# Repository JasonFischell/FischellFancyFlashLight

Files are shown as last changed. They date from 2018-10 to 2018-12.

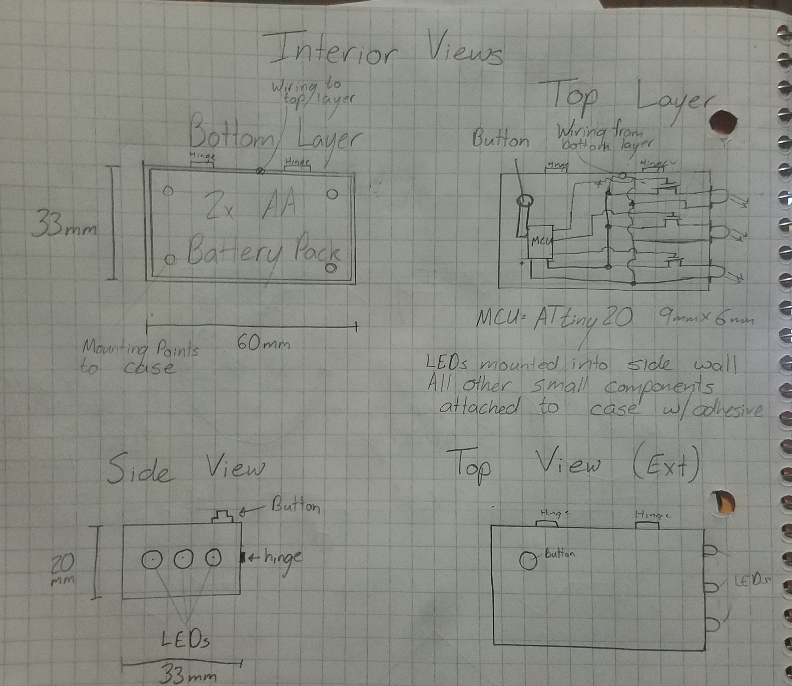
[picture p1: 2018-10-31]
Mechanical/Milestone 2/Original Flashlight Schematic.jpg

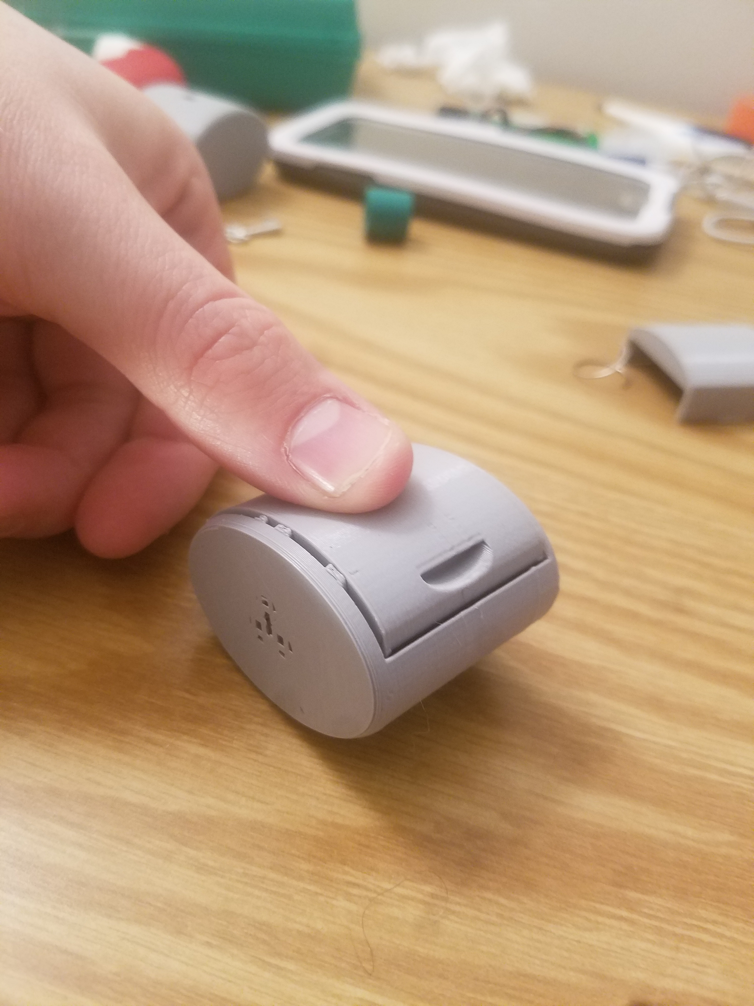
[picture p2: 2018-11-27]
Testing/Hardware Testing/20181126_164808.jpg

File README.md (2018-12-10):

# FischellFancyFlashLight

## Mechanical
A 3D printed case was designed to minimize the size of the device while maintaining a comfortable shape and relative stability. The dimensions are 1.2"x1.8"x2", with a 0.33" deep alcove for the 3 LEDs. The button is flush with the surface of the case, and debounce is performed in software, not hardware. The case is in two parts. The bottom is larger, containing conical holes to for ease of insertion of the LEDs and buttons, and four corner standoffs for the PCB. There are also two alcoves in the bottom for clips to attach the top to the bottom, and two semicircular holes of 0.4" diameter for pinching the top of the case to release the clasps. The top is smaller, with 0.01" of clearance on all sides to fit in the 1.3"x1.5" hole. The clips themselves have 0.05"x0.01"x0.01" clearance on all sides. Printed with 0.8mm wall thickness, 0.2mm layers, and 8% infill, the fit is incredibly tight, making the case very durable without any connective materials. The PCB cannot rattle around in the case due to the tightness and the conical standoffs, and neither can the top relative to the bottom. The case is so durable that it can be thrown at an 8 foot ceiling and fall on to linoleum without any damage. 

## Electrical 
The PCB is 1.25"x1.1" with a 0.05" hole in each corner for the standoffs. The three white (roughly 3.1V voltage drop) LEDs are driven by a MOSFET and connected in series with 10 Ohm resistors. The entire system is controlled by an ATTiny85, which is put into sleep mode for power conservation in the off state. Finally, there are 6 pins connected to the 6 programming pins on the ATTiny so that it can be reprogrammed at any point. A voltage regulator drops the voltage from roughly 6V to 3V, but the system works with a single 3V battery as well. The flashlight has current draws and theoretical battery lives are as follows:

						Battery Life (2 series,	Battery Life 
State:	Current Draw:	320 mAh CR2430):		(1, 1 Ah CR2477): 
Off		34.81 uA		9193 hr = 383 days		28727 hr = 1197 days = 3.28 years
Low		7.300 mA		43.8 hr = 1.83 days		137.0 hr = 5.71 days
Med		22.515 mAh		14.2 hr = 0.59 days		44.41 hr = 1.85 days
High	62.198 mAh		5.14 hr = 0.21 days		16.08 hr = 0.67 days
Flash 	4 mA - 62 mAh	9.70 hr = 0.40 days		30.30 hr = 1.26 days

## Software 
The code is incredibly simple, with interrupts for the button presses, PWM to controll LED brightness, and simple time difference calculation to prevent two button presses within 50 ms (to prevent button bouncing). To reprogram the flashlight, disconnect the batteries and connect the pins on the ribbon cables as follows:

Color: 		ATTiny Pin (PB pin, Mech.):		Arduino Pin:
Red 		Reset (NA, 1) 					Pin 10
Orange 		SCK (2, 7)						Pin 13
Yellow 		MISO (1, 6)						Pin 12
Green		Vcc	(NA, 8)						Power (3.3V or 5V)
Blue 		MOSI (0, 5)						Pin 11
Purple		Ground (NA, 4)					Ground

## Testing 
Every flashlight case ever printed was immeadiately drop tested. The electronic hardware was tested on a breadboard, and the current was tested using a high precision multimeter and an laboratory power supply (see above).

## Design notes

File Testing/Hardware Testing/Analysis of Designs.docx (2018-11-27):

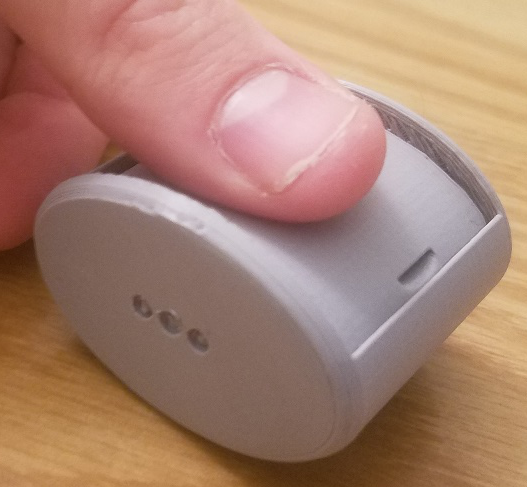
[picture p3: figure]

Velcro Design 1 (left): This case was designed to be held together by Velcro between the top and bottom pieces. The width of two layers of Velcro was guessed at 0.25”, but this proved to be roughly 0.15” too large, as indicated by the fact that top is not flush with the top of the outer casing.

Separation was to be achieved by inserting fingernails into the slits on either side of the top. However, 0.3” was not nearly wide enough (see thumb for scale) and the depth of 0.1” (bottom) was also too shallow.

Finally, the 3 LEDs were intended to be places in a row, but this design was later revised.

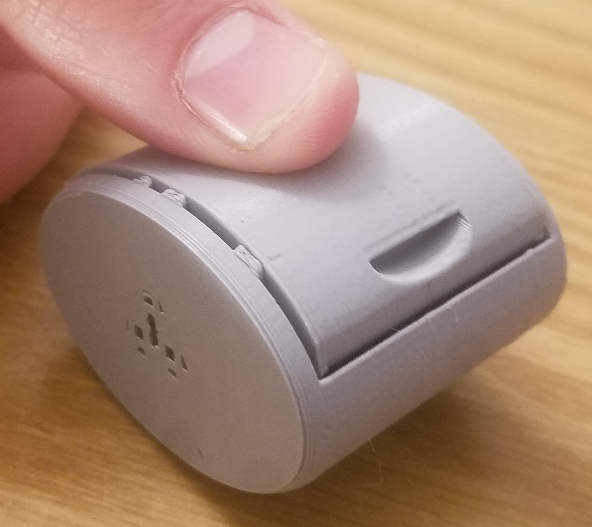
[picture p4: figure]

Velcro Design 2 (right): Same as the above, but the width of strips of Velcro was adjusted so that the top would be flush with the top of the outer casing.

The nail indents were doubled in width to 0.6” and the depth was increased to 0.15”, making the indents comfortable to grip with most fingers.

Next, the top was made wider to accommodate the increased depth of the fingernail indents.

Finally, the configuration of the 3 LEDs was changed, but this did not print correctly. This was fixed in future generations.

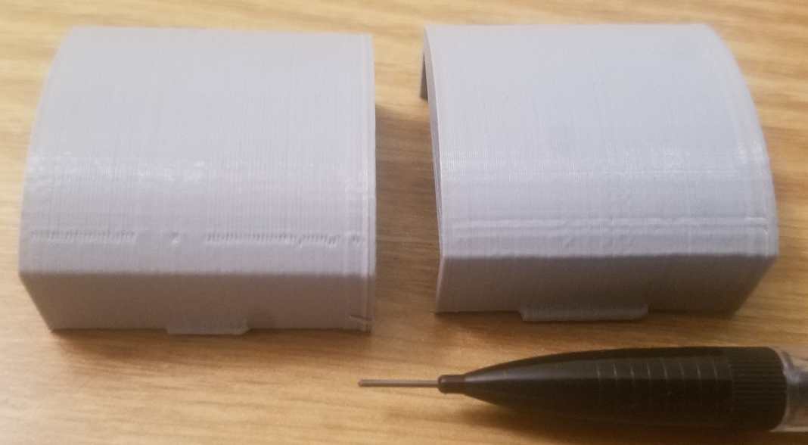
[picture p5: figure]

Clip Design 1 (left) and 2 (right):

The clip design is very similar to the Velcro, with the exception of the fastening method. On the left, there is a 0.3”x0.03”x0.03” protrusion on either side of the top, with a corresponding (but slightly larger) indent on either side of the bottom. This was too loose, and so in generation 2, the protrusion was adjusted to 0.5”x0.05”x0.05”. This fits tightly into the larger holes on the bottom of the housing, making the top removable, but difficult to remove. Both protrusions possess a 0.03” fillet to increase structural integrity. 0.7mm lead is shown for scale.

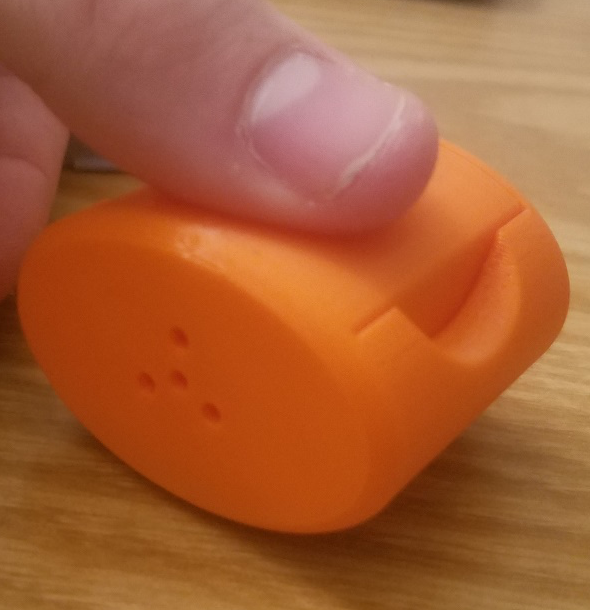
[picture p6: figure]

3D Printer Settings for Clip Design 2:

As is shown in this image, the bottom contains 1 holes for the 3 signal wires of the 3 LEDs on the front (outside) and 1 central hole for the common ground wires of the LEDs, placing them in a circular pattern on the face of the flashlight. The bottom has a semicircular 0.8” diameter hole cut in either side, 0.05” above the indentation for the clips protruding from the top. These holes allow the user to pinch the sides of the top together, thereby removing the protrusions from their holes and allowing the top to be removed. The thumb, shown for scale, was the appropriate width for such protrusions.

The remaining question is what 3D printer settings allow sufficiently easy bending of the top piece to remove the protrusions from the holes in the bottom, without jeopardizing the structural integrity of the casing. It was determined that wall width (0.4 mm vs. 0.8 mm) played a much bigger role in flexibility and integrity than infill. The 0.4 mm wall width top can easily be removed by pinching the sides of the top and pulling, whereas the 0.8 mm wall width top requires an inordinate amount of force (or the use of a screwdriver to pry it open) to remove the top. In the end, the choice between these two is somewhat arbitrary, but I am leaning toward the 0.8 mm wall width in the hope that it will be able to survive a fall from any height due to its relatively low terminal velocity.

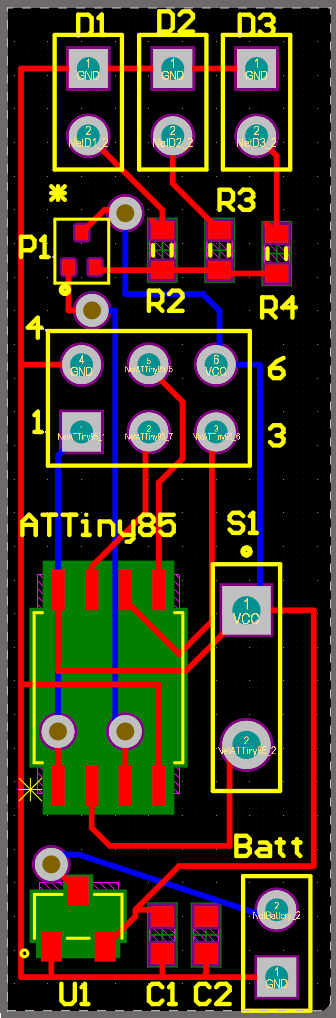
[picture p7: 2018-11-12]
Electronics/Milestone 4/PCB.png

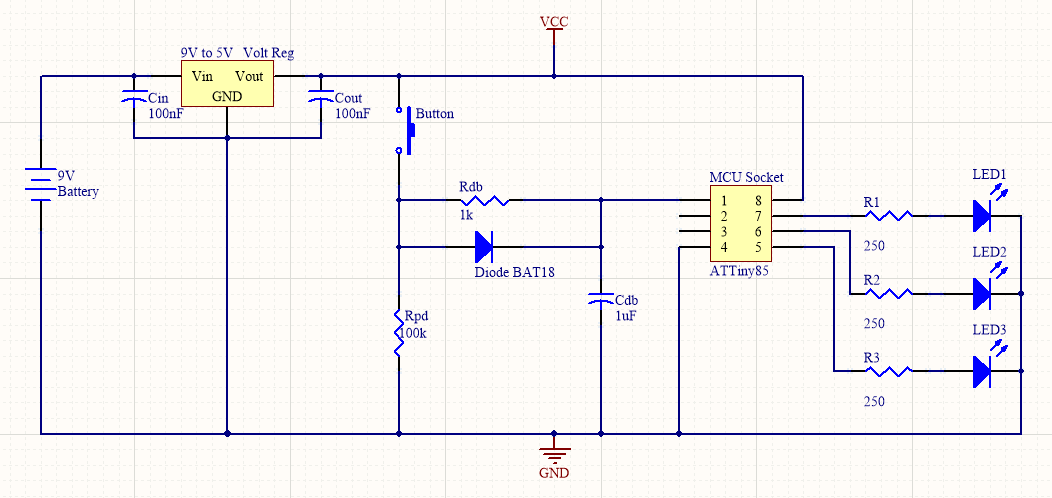
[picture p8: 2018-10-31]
Electronics/Milestone 3/Milestone_3_-_Schematic.png

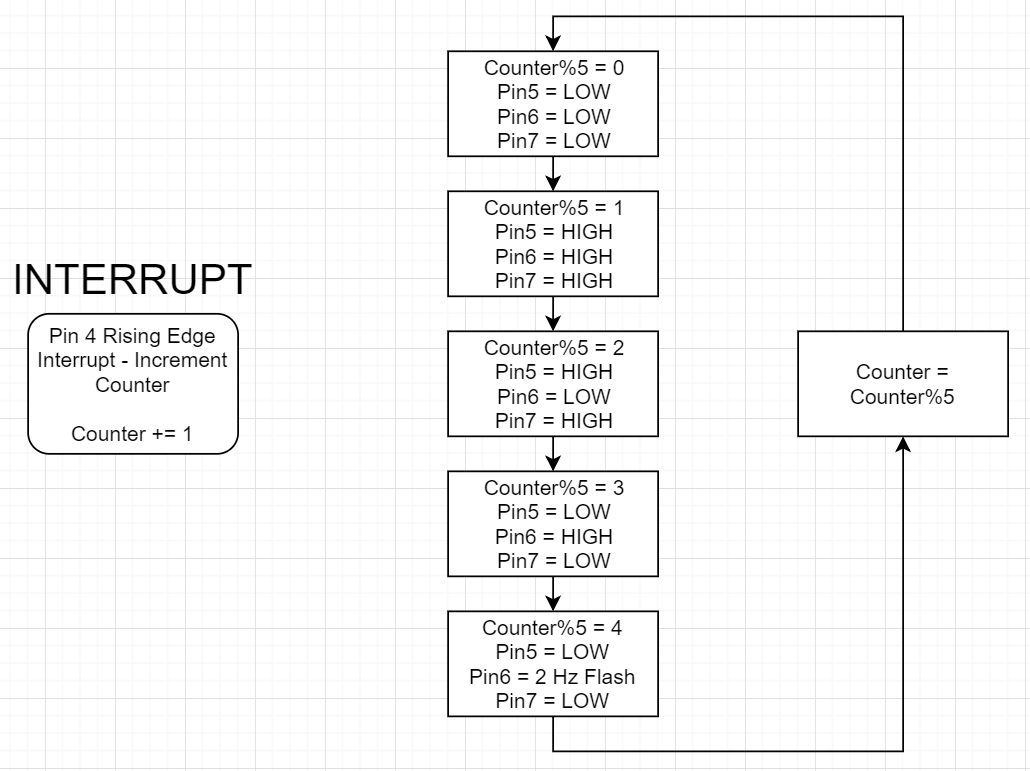
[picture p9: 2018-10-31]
Software/Milestone 3/Milestone_3_-_Software_Flowchart.png

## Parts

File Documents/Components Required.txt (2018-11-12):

Components required:
Already Have:
ATTiny85
Button

Need:
5 ohm resistor 0603 .25 W x3
100 kohm resistor 0603 0.1W x1
1 uF capacitor 0603 x2
Schottky diode 0603 with smallest voltage drop/power consumption possible x3

Battery Holder x3
https://www.digikey.com/product-detail/en/keystone-electronics/1025/36-1025-ND/49949

TVS Diode 
https://www.digikey.com/product-detail/en/littelfuse-inc/SMAJ5.0A/SMAJ5.0ALFCT-ND/762462

Linear Regulator 3.3 V
https://www.digikey.com/product-detail/en/diodes-incorporated/AP2120N-3.3TRG1/AP2120N-3.3TRG1DICT-ND/4505261

N-Channel MOSFET
https://www.digikey.com/product-detail/en/rohm-semiconductor/RE1C002UNTCL/RE1C002UNTCLCT-ND/5042535

White led through hole (non-specific at this point) x3

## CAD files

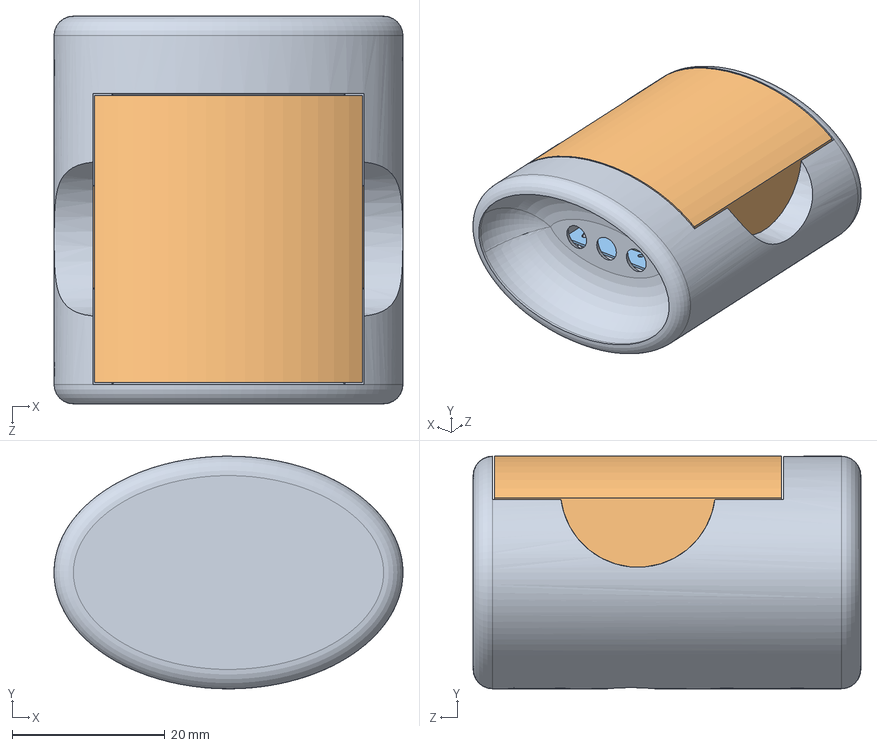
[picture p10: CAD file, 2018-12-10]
Mechanical/Milestone 5/Assem1.SLDASM
45.7 x 30.5 x 50.8 mm
Final Case Bottom
Final Case Top
Board_1
keystone-PN1025-7_1
SOT23-3_1
Extruded_1
Extruded_1_2 x 3
Extruded_1_3
Extruded_1_4
Extruded_1_5
8S2_1

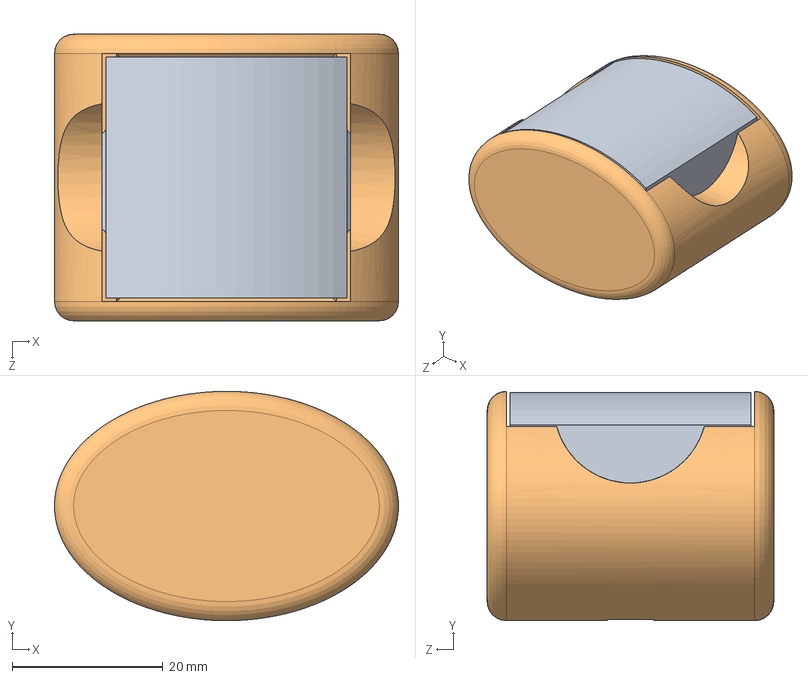
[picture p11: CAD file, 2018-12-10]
Mechanical/Milestone 5/Clip Assembly.SLDASM
45.7 x 30.5 x 38.1 mm
Clip Top
Clip Bottom
Board_1
keystone-PN1025-7_1
SOT23-3_1
Extruded_1
Extruded_1_2 x 3
Extruded_1_3
Extruded_1_4
Extruded_1_5
8S2_1

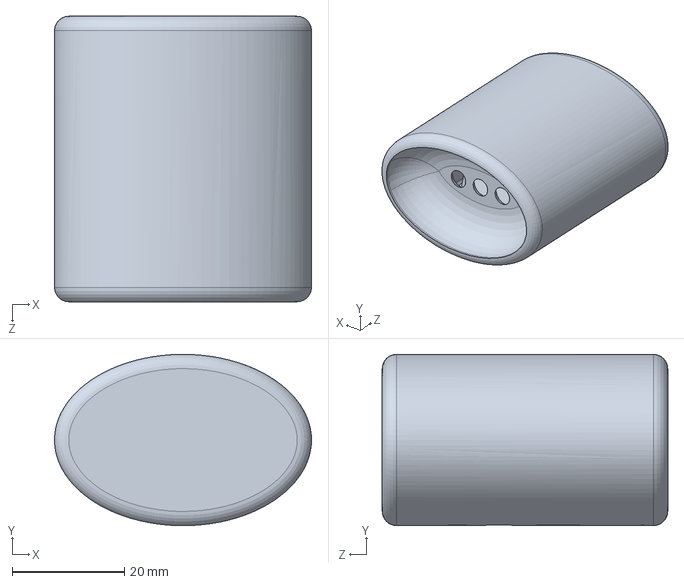
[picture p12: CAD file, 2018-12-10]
Mechanical/Milestone 5/Whole Final Case.SLDPRT
45.7 x 30.5 x 50.8 mm

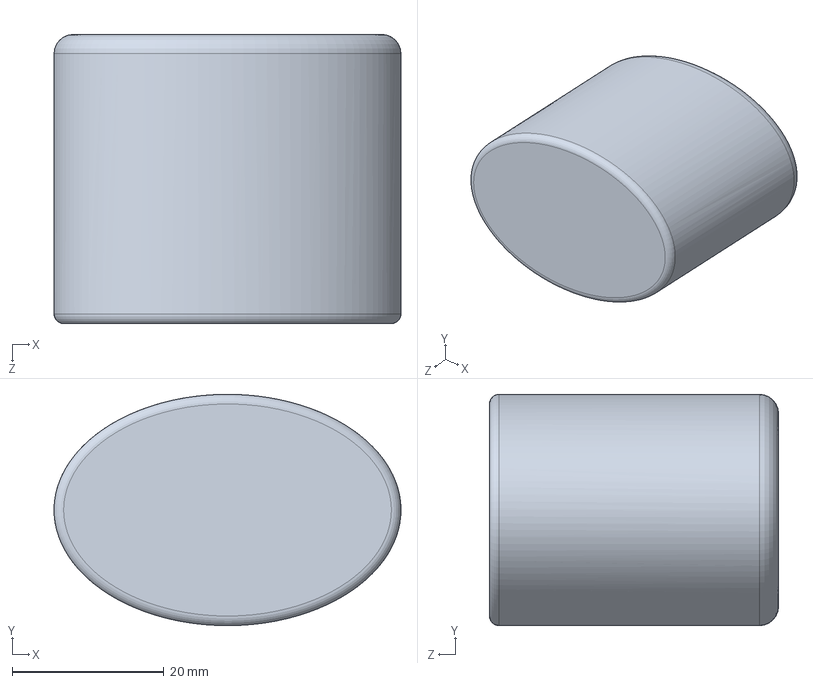
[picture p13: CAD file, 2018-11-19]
Mechanical/Milestone 5/Whole Case Incomplete.SLDPRT
45.7 x 30.5 x 38.1 mm

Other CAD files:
Mechanical/Milestone 5/U1_1.sldasm
Mechanical/Milestone 5/C2_1.sldasm
Mechanical/Milestone 5/C1_1.sldasm
Mechanical/Milestone 5/Imported_1.sldasm
Mechanical/Milestone 5/R3_1.sldasm
Mechanical/Milestone 5/R4_1.sldasm
Mechanical/Milestone 5/R2_1.sldasm
Mechanical/Milestone 5/R1_1.sldasm
Mechanical/Milestone 5/ATTiny85_1.sldasm
Mechanical/Milestone 5/Velcro Assembly.SLDASM
Mechanical/Milestone 5/Successful Assembly.SLDASM
Mechanical/Milestone 5/R1.sldasm
Mechanical/Milestone 5/C1.sldasm
Mechanical/Milestone 5/C2.sldasm
Mechanical/Milestone 5/4438510656.sldasm
Mechanical/Milestone 5/4438510848.sldasm
Mechanical/Milestone 5/4438511040.sldasm
Mechanical/Milestone 5/4438511232.sldasm
Mechanical/Milestone 5/4438511424.sldasm
Mechanical/Milestone 5/5808184704.sldasm
Mechanical/Milestone 5/5808184896.sldasm
Mechanical/Milestone 5/5808185088.sldasm
Mechanical/Milestone 5/5808185280.sldasm
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

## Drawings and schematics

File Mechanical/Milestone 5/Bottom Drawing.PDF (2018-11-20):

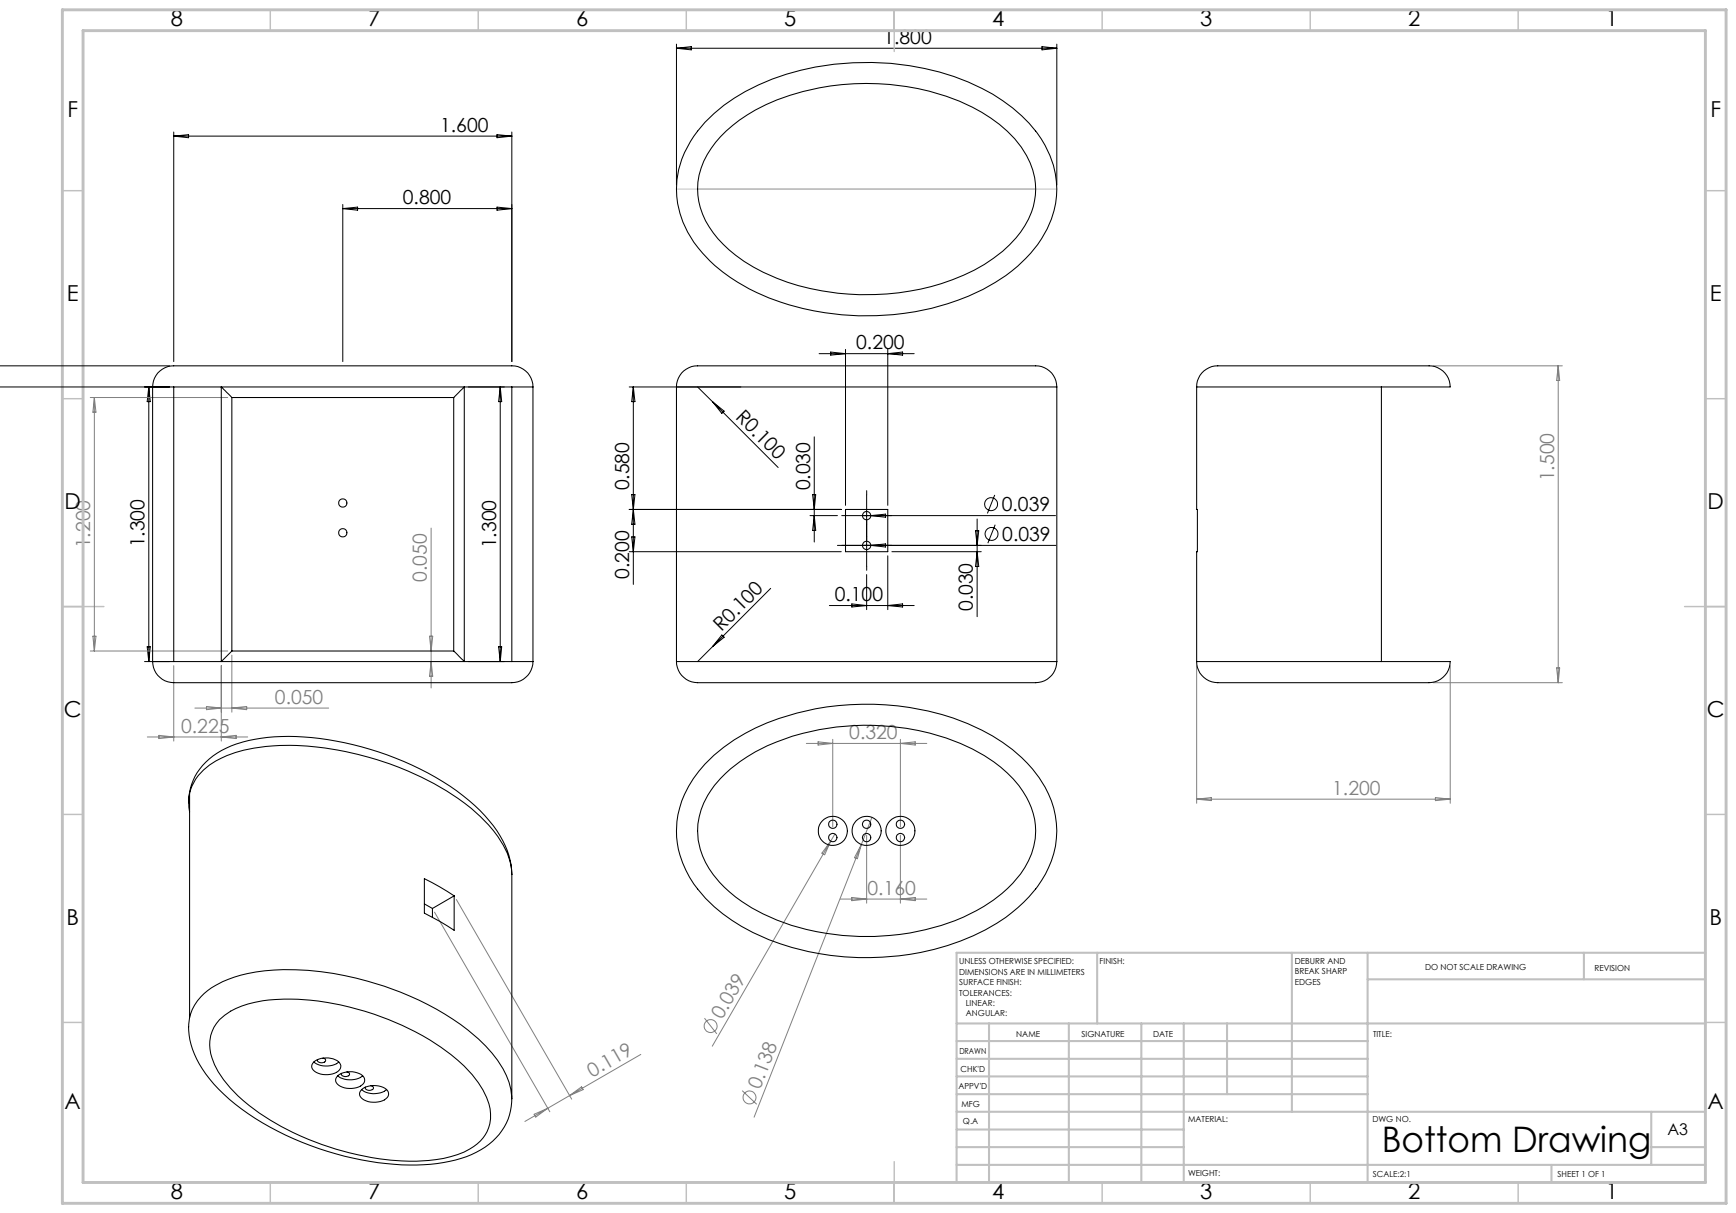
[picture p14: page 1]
FINISH:; DEBURR AND; BREAK SHARP; DO NOT SCALE DRAWING; REVISION; SCALE:2:1; SHEET 1 OF 1

UNLESS OTHERWISE SPECIFIED:
DIMENSIONS ARE IN MILLIMETERS
SURFACE FINISH:
TOLERANCES:
LINEAR:
ANGULAR:

NAME | SIGNATURE | DATE | | | | TITLE:

DRAWN
CHK'D
APPV'D
MFG
Q.A | | | | MATERIAL: | DWG NO. Bottom Drawing | A3

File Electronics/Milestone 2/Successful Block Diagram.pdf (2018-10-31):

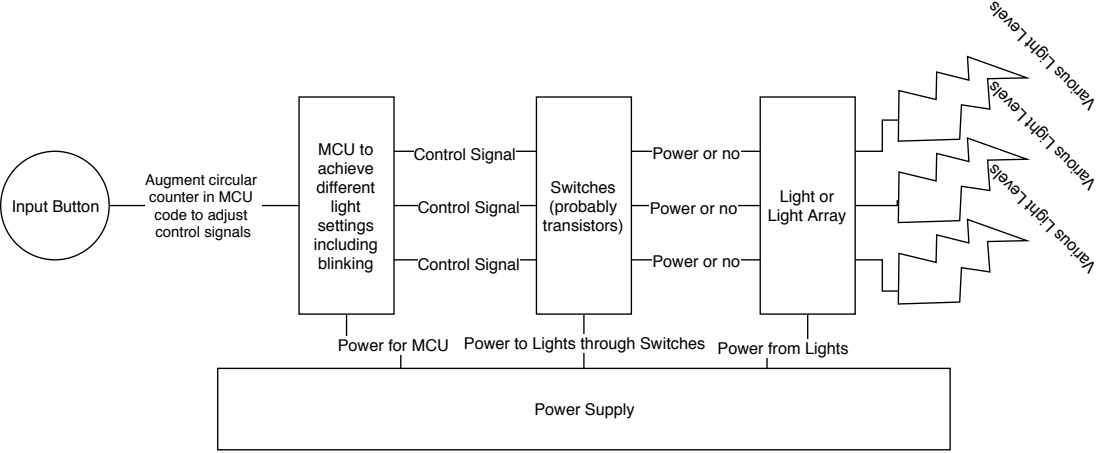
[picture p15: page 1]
Power Supply; Light or Light Array; Switches (probably transistors); Control Signal; MCU to achieve different light settings including blinking; Input Button

Various Light Levels

Power or no

Augment circular
counter in MCU
code to adjust
control signals

Power for MCU

Power from Lights Power to Lights through Switches

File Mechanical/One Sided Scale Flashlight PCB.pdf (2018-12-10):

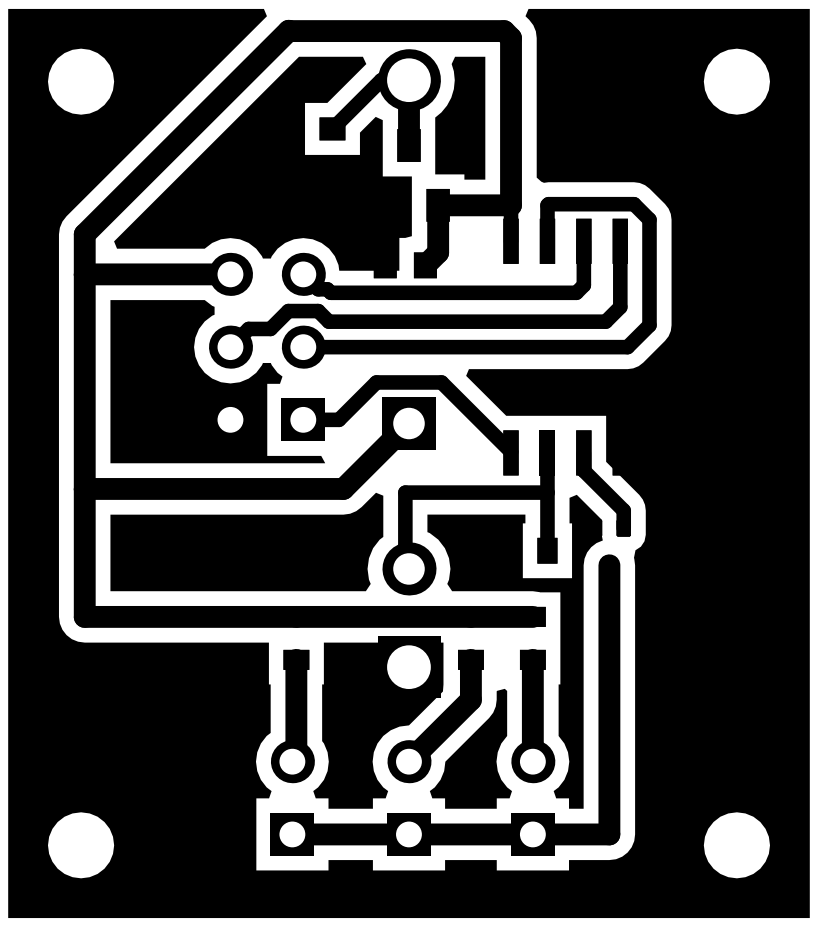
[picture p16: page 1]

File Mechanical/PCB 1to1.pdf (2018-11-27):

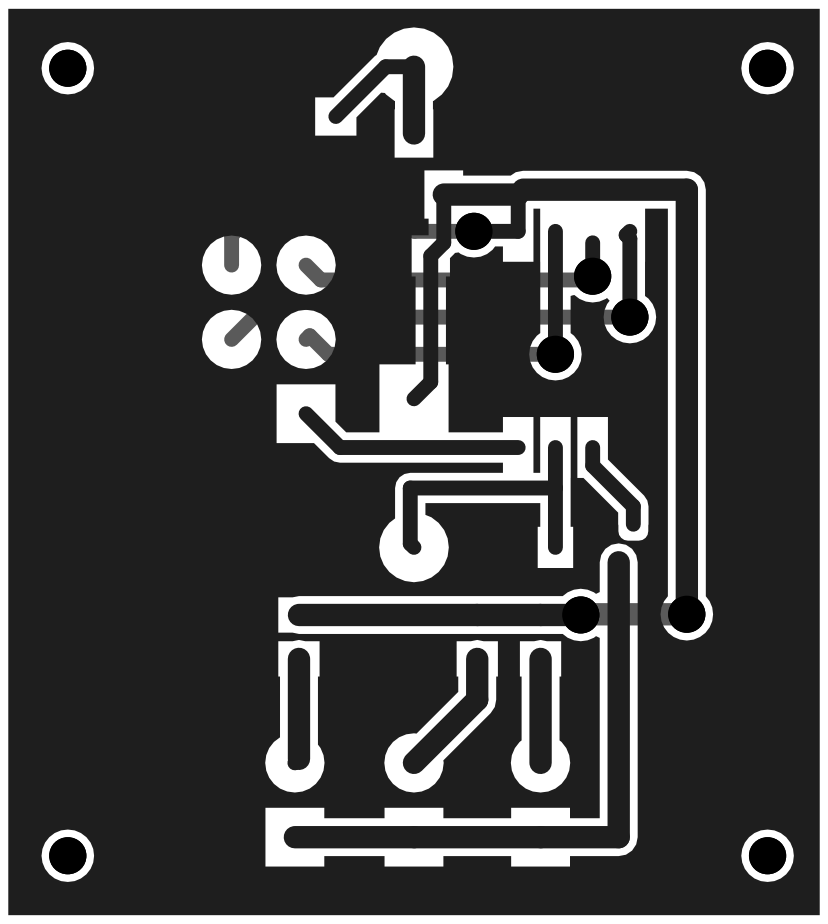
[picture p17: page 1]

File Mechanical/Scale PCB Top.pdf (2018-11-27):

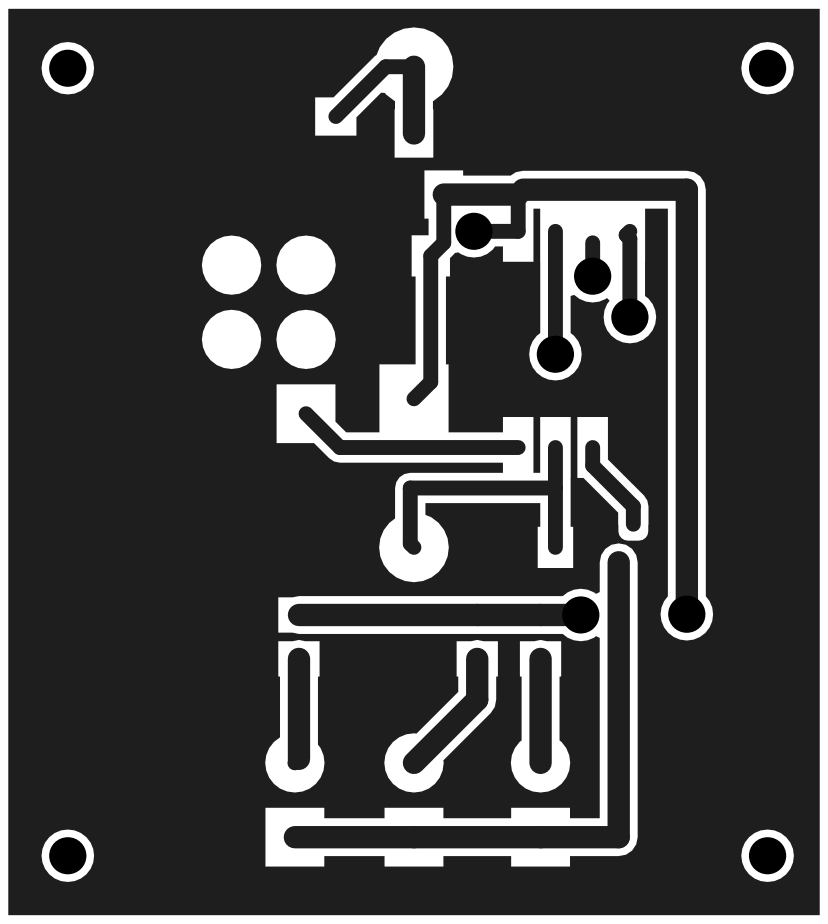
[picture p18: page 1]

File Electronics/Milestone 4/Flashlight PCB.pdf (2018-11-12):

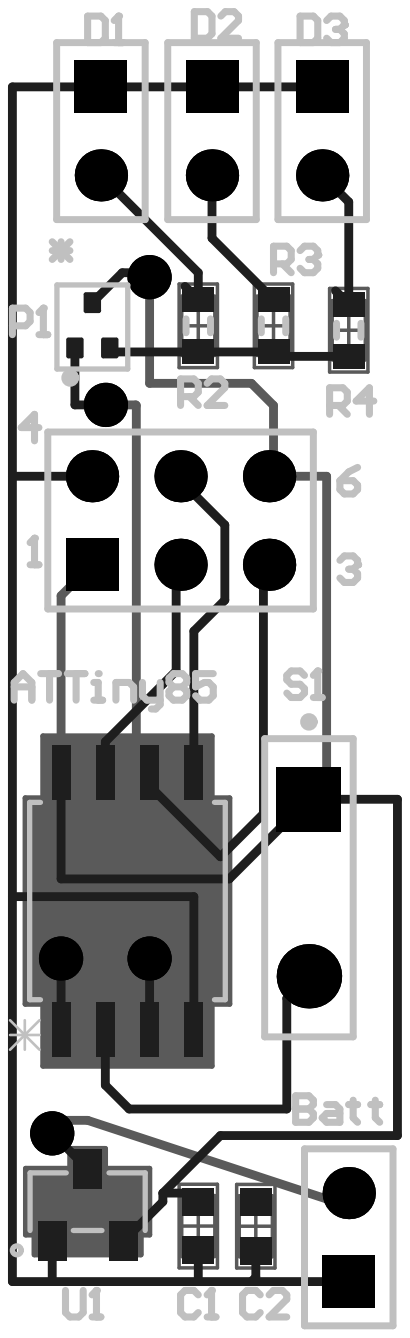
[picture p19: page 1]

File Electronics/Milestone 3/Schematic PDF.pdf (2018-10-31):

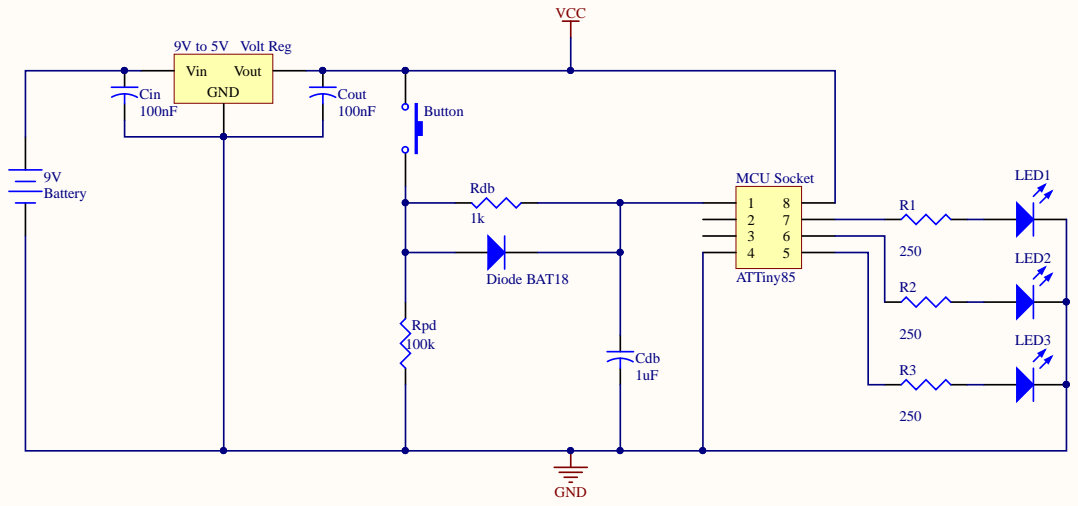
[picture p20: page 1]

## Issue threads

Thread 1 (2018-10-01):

Sketch Physical Design

JasonFischell, 2018-10-01:
-Relevant Approx Dimensions
-Mounting points for internal parts
-Access for battery
-Consider what aspects of the device need to be accessible to the user during operation

Closed 2018-10-02.

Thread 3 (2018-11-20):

Oops... Mechanical and Electrical CAD issue

JasonFischell, 2018-11-20:
Sorry. Both are done now. I didn't realize we were supposed to create issues for some reason. My bad.

ps178, 2018-11-21:
Hi Jason,

You have a lot of files under your Milestone 5 folder. Could you more clearly label which file is your final case CAD to be reviewed :)

JasonFischell, 2018-11-26:
This has been revised since then. Let me make it a little clearer. But first, do you want drawings or just CAD files?

mlp6, 2018-11-26:
@JasonFischell looking good... I will let @ericsrichardson comment on the finer aspects of this design too, but from my perspective this is shaping up nicely.  I'm a little concerned that our printers may not capture some of the smaller features well, specifically some of the insets that might get filled with some supports.

JasonFischell, 2018-11-26:
Dr. Palmeri,

I have already printed 4 different generations and they all work as planned. I'm not sure if you looked at the "Thick" Clip design, but that is the one I am going for and it worked really well. The only thing I am worried about is my PCB. Does that look good to you?

Thanks,
Jason

JasonFischell, 2018-11-27:
Update: I am going to change all traces to at least 20 mils. Hopefully I'll be able to print Wednesday, if that works for Matt Brown. I'll send him an email confirming tonight or tomorrow.

mlp6, 2018-11-27:
Yep, you still have some 10 mil traces in there that will be too narrow for the photoetch; otherwise I think it looks good!

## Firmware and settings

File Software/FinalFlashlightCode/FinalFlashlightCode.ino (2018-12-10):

/*
 * FinalFlashlightCode.ino
 * Jason Fischell & Greg Goldman
 * BME 590: Medical Instrumentation Design
 * Fall, 2018
 * 
 * This code operates a flashlight on an ATTiny85 processor at a clock speed of 8 MHz
 * It is capable of 5 modes: low, medium, high, flash at high, and off
 * When off, the processor is put to sleep, reducing its current draw from a few mA
 * to around 50 uA.
 * 
 * It uses interrupts to record button inputs, and it has rudimentary software debounce 
 * built in.
 * 
 * A great challenge with the debounce was that the timer resets after going to sleep, so
 * it was hard to tell the time since the last press if the device had slept. This was solved
 * by implementing a delay of the bounce wait time before going to sleeep. 
 * 
 * All time variables are in microseconds because micros() works in the ISR, but millis doesn't
 * 
 * In an unsigned long, there are 2^32 bits, so I can count to about 4.295 billion microseconds,
 * or about 4295 seconds, which is about 2.98 days before the timer count can roll over
 * 
 * Related content can be found at https://github.com/GregGoldman/BlinkLight
 */

//Includes
#include <avr/io.h> 
#include <avr/interrupt.h> //https://www.nongnu.org/avr-libc/user-manual/group__avr__interrupts.html
#include <avr/sleep.h> //https://www.nongnu.org/avr-libc/user-manual/group__avr__sleep.html
//https://bigdanzblog.wordpress.com/2014/08/10/attiny85-wake-from-sleep-on-pin-state-change-code-example/
// how to put attiny to sleep

int LEDPIN = 4;
int BUTTONPIN = 3;
bool Flash = LOW;
volatile int State = 0;


volatile int pressCount = 0;
/*
   0: off
   1: low
   2: med
   3: high
   4: 2Hz blink at high intensity
*/

///online sources suggest to declare variables which go in the ISR as volatile
unsigned long bounceTime = 50000; // how long to wait to avoid bounce: 200 ms
volatile unsigned long now = 0; //current time
unsigned long lastFlashTime = 0; // previous time
volatile unsigned long lastPressedTime = 0;

void setup() {
  // sets PB4 to output, all others to inputs
  DDRB  = 0b00010000;

  //disable pullup on PB3 and PB4
  PORTB = 0b11100111;

  // set all outputs to low first (default, likely unecessary)
  PINB = 0b00000000;

  //disable interrupts during setup
  cli();
  // choose PB 3 for your interrupt pin
  PCMSK = 0b00001000;
  // globally stage change interrupts to be enabled (still requires sei())
  GIMSK = 0b00100000;

  ADCSRA &= ~_BV(ADEN);  // ADC off

  //enable interrupts after setup
  sei();
}

void loop() {
  // only increment the State at the top of the loop so it can't change during 
  // the Switch Tree or other inconvenient places
  if (pressCount > 0) {
    State += 1;
    if (State > 4) {
      State = 0;
    }
    pressCount = 0;
  }
  
  switch (State) {
    case 0:
      analogWrite(LEDPIN, 0);
      // the longest accurate microsecond delay is 16383 according to arduino.cc
      // as such, use delay() instead
      // this is one of the rare cases we are OK with a delay.
      delay(bounceTime/1000);
      set_sleep_mode(SLEEP_MODE_PWR_DOWN);
      sleep_enable();
      sleep_cpu();
      break;
    case 1:
      sleep_disable(); // not entirely sure this line is needed
      analogWrite(LEDPIN, 20);
      break;
    case 2:
      analogWrite(LEDPIN, 100);
      break;
    case 3:
      analogWrite(LEDPIN, 255);
      break;
    case 4:
      now = micros();
      if (now - lastFlashTime > 250000) {
        Flash = !Flash;
        lastFlashTime = now;
      }
      if (Flash) {
        analogWrite(LEDPIN, 255);
      }
      else {
        analogWrite(LEDPIN, 0);
      }
      break;
    default:
      analogWrite(LEDPIN, 0);
      break;
  }
}

//Pin Change Interrupt Request 0 (don't look at nested interrupts)
ISR(PCINT0_vect) {
  // This will trigger on both rising and falling by default
  // need to read the state of the pin to tell if rising
  now = micros();
  if (digitalRead(BUTTONPIN)) {
    if (now - lastPressedTime > bounceTime || State == 0) {
      pressCount += 1;
    }
  }
  lastPressedTime = micros();
}

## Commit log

2018-10-31 Milestone 3 - Schematics and Software Flow Chart
    Everything summarized in PDF. Additional: Pseudo Code
    [181031 Schematic.SchDoc]
2018-10-31 Milestone 3 Commit to Proper Folders
    Schematic
    Software Flow Chart
    Document Containing the above + Pseudo COde
    [181031 Schematic.SchDoc]
2018-10-31 Final Rearrangements of Everything Uploaded So Far
    Sorry, GitHub is Hard
    [181031 Schematic.SchDoc]
2018-11-12 Milestone 4 - PCB Commit
    Hopefully this includes everything you need. The PDF is hard to read, but the actual file is there and PCB.png should also be easy to interpret.
    [181031 Schematic with PCB.SchDoc, ATTinyPCB.PcbLib, ATTinyPCBJason.PcbLib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]
2018-11-19 Milestone 5 - Casing/Hardware
    Just two pieces, top and bottom, connected by velcro. See Assembly.
    [181031 Schematic with PCB.SchDoc, 4438510656.sldasm, 4438510848.sldasm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]
2018-11-20 Addition of Drawings
    I'm not entirely sure how we were supposed to do this...
    [Successful Assembly.SLDDRW]
2018-11-20 Fixed Top and Bottom, Added Drawings
    Drawings of both individual parts are available, as well as the completed assembly for redundancy.
    [Bottom Drawing.SLDDRW, Bottom.SLDPRT, Successful Assembly.SLDASM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]
2018-11-26 Updated Hardware
    Designed two independent models of casing, clip and velcro. Both models have gone through 2 generations of revisions. The conclusion is that "Thick Clips" are the way to go. This is probably the hous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
    [Bottom.SLDPRT, Bottom.STL, Clip Assembly.SLDASM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]
2018-11-27 Final Flashlight PCB
    This should work...
    [Final Flashlight PCB.PcbDoc, Final Flashlight PCB.step, Flashlight PCB 2.PcbDoc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]
2018-11-27 Testing - Analysis of Hardware Designs
    Hardware Design analysis based on testing and playing with 4 different 3D printed designs, and 2 different 3D printer settings for the final design. 1 video of the circuit functioning as intended in 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
2018-11-27 Scale PCB Layers for Photoetching
    Thoughts Matt Brown?
    [Final Flashlight PCB.PcbDoc, Flashlight PCB.PrjPCB]
2018-11-28 One Sided PCB
    Edited PCB to put all traces on 1 side for ease of photoetching.
    [Copy of Final Flashlight PCB.PcbDoc, Final Flashlight PCB.PcbDoc, Flashlight PCB.PrjPCB]
2018-11-28 Finalizing (hopefully) Mechanical CAD
    Added pressure fitted standoffs to bottom of clip casing, added complete, final (hopefully) PCB model to mechanical CAD, and created an assembly to show everything fitting together. Assuming high pri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
    [5808184704.sldasm, 5808184896.sldasm, 5808185088.sldasm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]
2018-12-10 Final Commit
    CAD updates mostly, and a full readme.
    [5808184704.sldasm, 5808184896.sldasm, 5808185088.sldasm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]
